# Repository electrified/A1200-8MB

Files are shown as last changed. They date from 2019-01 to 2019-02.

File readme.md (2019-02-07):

# 8MB Fast Ram for A1200

This is a 8MB FastRam board for A1200 designed in 2019 by @edu_arana, coworked with Stephen Leary based on the TF328 project.

# License

This project, as the same as the original, are released under the GNU GPLv2. If you build a modified version of the board you must supply the end user with all the sources (this can be a web link). Also you may create
or base commercial PCBs from the work in this repository but you must make the sources for all derivative work available. The authors on this board must remain and stay legible on the current / new board. Removing the
copyright notices its a breach of the GPL.

BTW, If you make a new board version, we will be glad if you send at least one pcb to each us. This is not a must :p

# Images

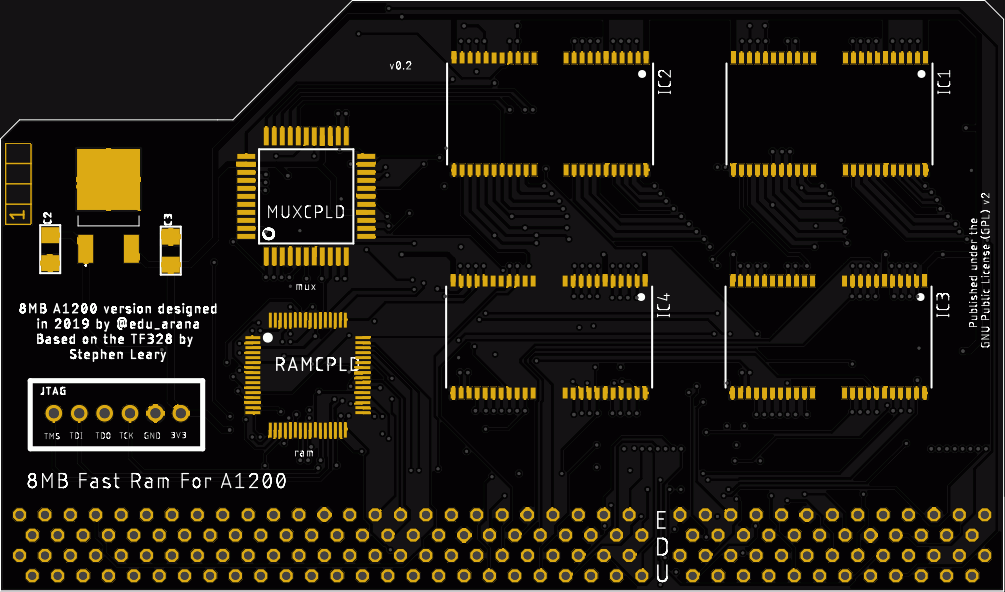
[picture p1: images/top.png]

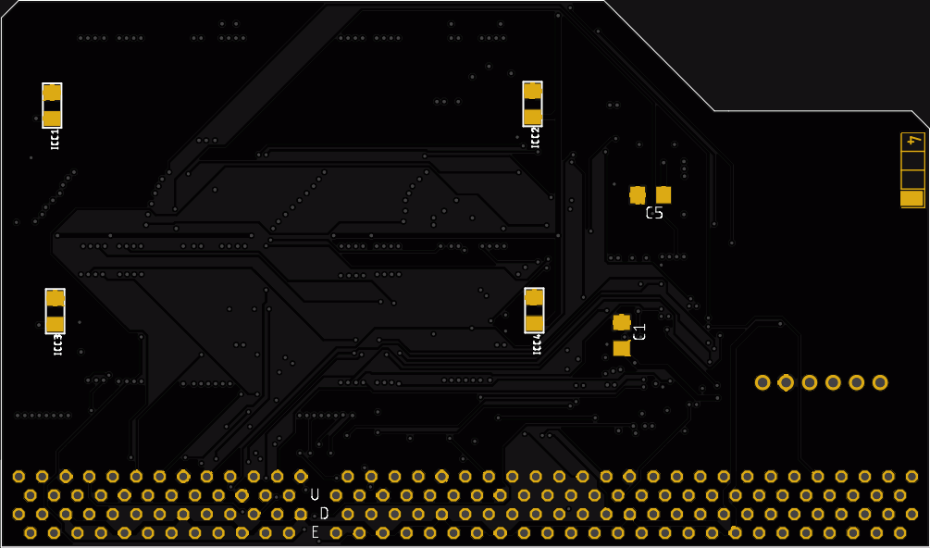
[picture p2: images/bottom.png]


# PCB info (for pcb fabricator)

Dimensions :	59 x 100 mm  
Layers :	4 layers  
Layer order: GTL, G1, G2, GBL  
Finished Copper : 1 oz Cu  
PCB Kinds:	2 (because the breakable area)  
Track/Spacing:	6/6mil  
Blind/Buried Via: No  
Material :	Normal FR-4 Board TG150  
Thickness :	1.6 mm  
Solder Mask :	Whatever color you want :)  
Silkscreen :	Whatever color you want :)  
Surface Finish :Immersion gold (recommended)  
Hole Size :	0.4  

# Firmware:

S. Leary a.k.a terriblefire has made an small modification to the current TF322 to disable the ide option, as the A1200 already have one. The firmware jed files are available on the firmware directory.

Xilinx ISE, 14.7
JTAG Adaptor

Stephen has made a new branch for the firmware used on this board. The current branch address is https://github.com/terriblefire/tf328/tree/edu1200_board

Thanks S.

# Gerbers:

Premade gerbers of the board are available on this repository too.

# Bill of matherials

Note that the only ram chips used and compatible are the K4E151612C, this ram chips are 3v3 only. All the current design is adapter to 3V3. A new LDO regulator is used to get 3V3 vots.

| Part | Value | Package |
| --- | --- | --- |
| C1 | 1uF | 1206 |
| C2 | 10uF | 1206 | 
| C3 | 10uF | 1206 | 
| C5 | 1uF | 1206 |
| CN1 | A1200-EXPANSION_SLOT | CON_150 | 
| IC1 | K4E151612C | TSOP44(50)-II | 
| IC2 | K4E151612C | TSOP44(50)-II | 
| IC3 | K4E151612C | TSOP44(50)-II | 
| IC4 | K4E151612C | TSOP44(50)-II | 
| IC6 | LD39150DT33-R | STD5N52U | 
| ICC1 | 10uF | 1206 | 
| ICC2 | 10uF | 1206 | 
| ICC3 | 10uF | 1206 | 
| ICC4 | 10uF | 1206 | 
| MUXCPLD | XC9536_44VQ | SQFP-S-10X10-44 | 
| RAMCPLD | XC9572XL-VQ64 | VQ64 |

# Wiki

There is a TF328 wiki that can be use to resolve any doubt about the compatibility of the current firmware.

https://github.com/terriblefire/tf328/wiki

# PCMCIA Fix

If you got problems with your PCMCIA device and this upgrade, you can use a free software solution available on aminet called CardReset http://aminet.net/package/util/boot/CardReset

# Contribution / support

If you wanna buy me a beer or a Mercedes SLR,  please contact me at info at arananet.net or support @terriblefire at youtube :)

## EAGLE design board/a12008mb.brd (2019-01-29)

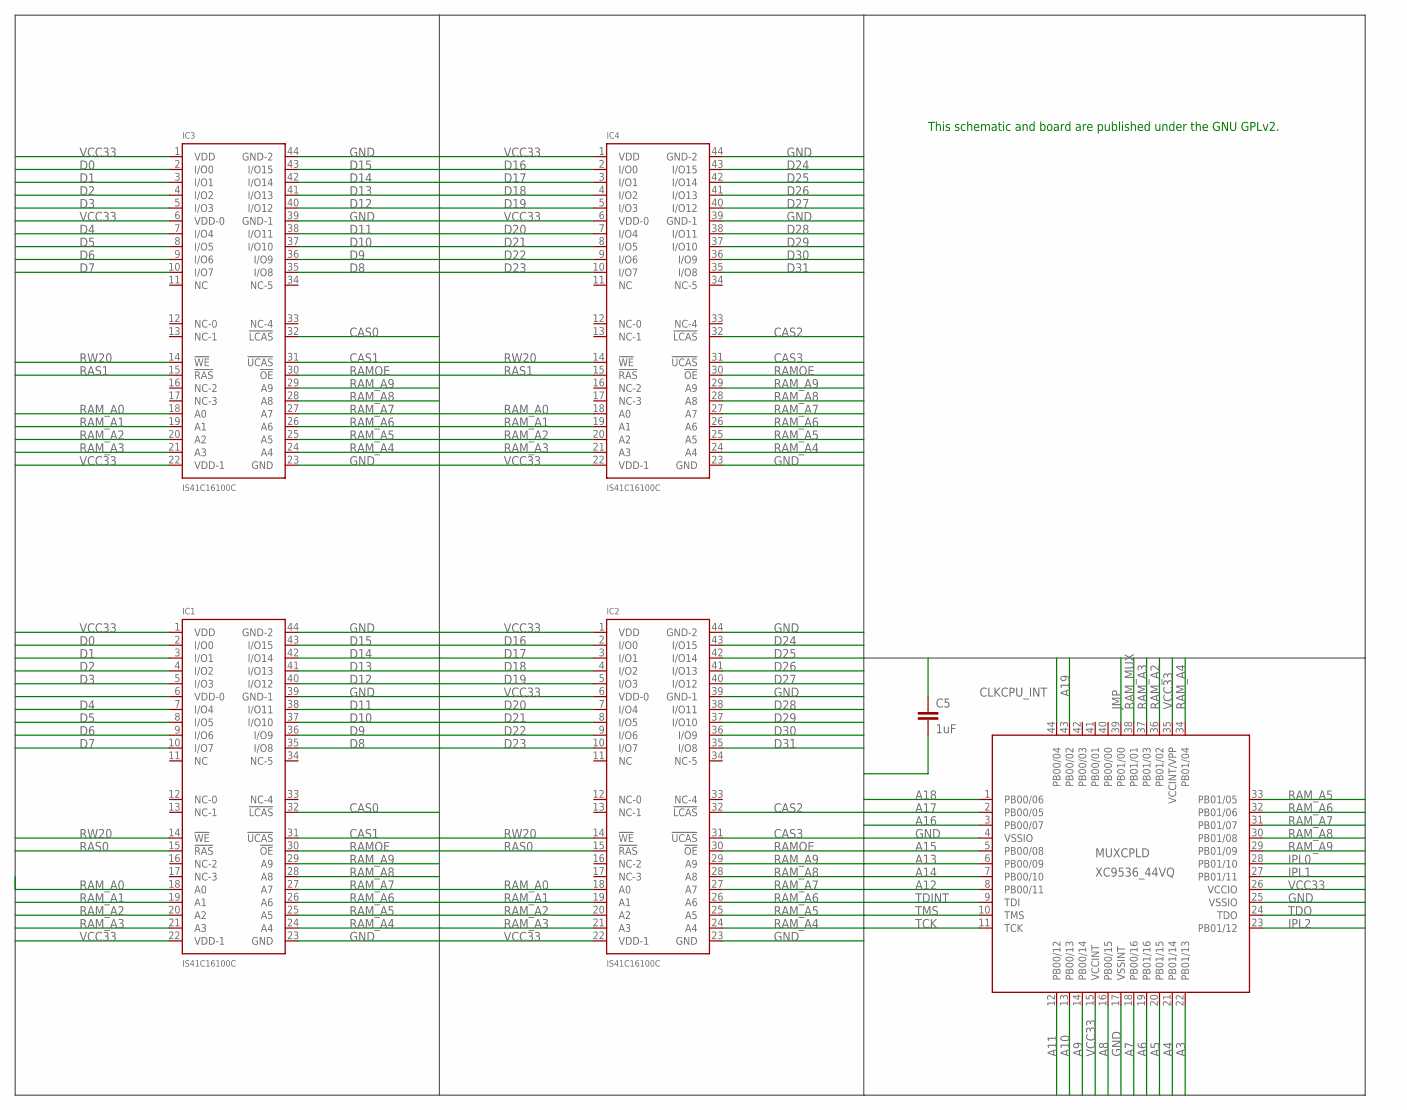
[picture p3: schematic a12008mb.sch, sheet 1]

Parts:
C5: 1uF; C1206
IC1, IC2, IC3, IC4: IS41C16100C; TSOP44(50)-II
MUXCPLD: XC9536_44VQ; SQFP-S-10X10-44

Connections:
A3: MUXCPLD.22 (PB01/13); also elsewhere on the board
A4: MUXCPLD.21 (PB01/14); also elsewhere on the board
A5: MUXCPLD.20 (PB01/15); also elsewhere on the board
A6: MUXCPLD.19 (PB01/16); also elsewhere on the board
A7: MUXCPLD.18 (PB00/16); also elsewhere on the board
A8: MUXCPLD.16 (PB00/15); also elsewhere on the board
A9: MUXCPLD.14 (PB00/14); also elsewhere on the board
A10: MUXCPLD.13 (PB00/13); also elsewhere on the board
A11: MUXCPLD.12 (PB00/12); also elsewhere on the board
A12: MUXCPLD.8 (PB00/11); also elsewhere on the board
A13: MUXCPLD.6 (PB00/09); also elsewhere on the board
A14: MUXCPLD.7 (PB00/10); also elsewhere on the board
A15: MUXCPLD.5 (PB00/08); also elsewhere on the board
A16: MUXCPLD.3 (PB00/07); also elsewhere on the board
A17: MUXCPLD.2 (PB00/05); also elsewhere on the board
A18: MUXCPLD.1 (PB00/06); also elsewhere on the board
A19: MUXCPLD.43 (PB00/02); also elsewhere on the board
CAS0: IC1.32 (!LCAS), IC3.32 (!LCAS); also elsewhere on the board
CAS1: IC1.31 (!UCAS), IC3.31 (!UCAS); also elsewhere on the board
CAS2: IC2.32 (!LCAS), IC4.32 (!LCAS); also elsewhere on the board
CAS3: IC2.31 (!UCAS), IC4.31 (!UCAS); also elsewhere on the board
CLKCPU_INT: MUXCPLD.44 (PB00/04)
D0: IC1.2 (I/O0), IC3.2 (I/O0); also elsewhere on the board
D1: IC1.3 (I/O1), IC3.3 (I/O1); also elsewhere on the board
D2: IC1.4 (I/O2), IC3.4 (I/O2); also elsewhere on the board
D3: IC1.5 (I/O3), IC3.5 (I/O3); also elsewhere on the board
D4: IC1.7 (I/O4), IC3.7 (I/O4); also elsewhere on the board
D5: IC1.8 (I/O5), IC3.8 (I/O5); also elsewhere on the board
D6: IC1.9 (I/O6), IC3.9 (I/O6); also elsewhere on the board
D7: IC1.10 (I/O7), IC3.10 (I/O7); also elsewhere on the board
D8: IC1.35 (I/O8), IC3.35 (I/O8); also elsewhere on the board
D9: IC1.36 (I/O9), IC3.36 (I/O9); also elsewhere on the board
D10: IC1.37 (I/O10), IC3.37 (I/O10); also elsewhere on the board
D11: IC1.38 (I/O11), IC3.38 (I/O11); also elsewhere on the board
D12: IC1.40 (I/O12), IC3.40 (I/O12); also elsewhere on the board
D13: IC1.41 (I/O13), IC3.41 (I/O13); also elsewhere on the board
D14: IC1.42 (I/O14), IC3.42 (I/O14); also elsewhere on the board
D15: IC1.43 (I/O15), IC3.43 (I/O15); also elsewhere on the board
D16: IC2.2 (I/O0), IC4.2 (I/O0); also elsewhere on the board
D17: IC2.3 (I/O1), IC4.3 (I/O1); also elsewhere on the board
D18: IC2.4 (I/O2), IC4.4 (I/O2); also elsewhere on the board
D19: IC2.5 (I/O3), IC4.5 (I/O3); also elsewhere on the board
D20: IC2.7 (I/O4), IC4.7 (I/O4); also elsewhere on the board
D21: IC2.8 (I/O5), IC4.8 (I/O5); also elsewhere on the board
D22: IC2.9 (I/O6), IC4.9 (I/O6); also elsewhere on the board
D23: IC2.10 (I/O7), IC4.10 (I/O7); also elsewhere on the board
D24: IC2.43 (I/O15), IC4.43 (I/O15); also elsewhere on the board
D25: IC2.42 (I/O14), IC4.42 (I/O14); also elsewhere on the board
D26: IC2.41 (I/O13), IC4.41 (I/O13); also elsewhere on the board
D27: IC2.40 (I/O12), IC4.40 (I/O12); also elsewhere on the board
D28: IC2.38 (I/O11), IC4.38 (I/O11); also elsewhere on the board
D29: IC2.37 (I/O10), IC4.37 (I/O10); also elsewhere on the board
D30: IC2.36 (I/O9), IC4.36 (I/O9); also elsewhere on the board
D31: IC2.35 (I/O8), IC4.35 (I/O8); also elsewhere on the board
GND: C5.2, IC1.23 (GND), IC1.39 (GND-1), IC1.44 (GND-2), IC2.23 (GND), IC2.39 (GND-1), IC2.44 (GND-2), IC3.23 (GND), IC3.39 (GND-1), IC3.44 (GND-2), IC4.23 (GND), IC4.39 (GND-1), IC4.44 (GND-2), MUXCPLD.4 (VSSIO), MUXCPLD.17 (VSSINT), MUXCPLD.25 (VSSIO); also elsewhere on the board
IPL0: MUXCPLD.28 (PB01/10); also elsewhere on the board
IPL1: MUXCPLD.27 (PB01/11); also elsewhere on the board
IPL2: MUXCPLD.23 (PB01/12); also elsewhere on the board
JMP: MUXCPLD.39 (PB01/00)
RAMOE: IC1.30 (!OE), IC2.30 (!OE), IC3.30 (!OE), IC4.30 (!OE); also elsewhere on the board
RAM_A0: IC1.18 (A0), IC2.18 (A0), IC3.18 (A0), IC4.18 (A0); also elsewhere on the board
RAM_A1: IC1.19 (A1), IC2.19 (A1), IC3.19 (A1), IC4.19 (A1); also elsewhere on the board
RAM_A2: IC1.20 (A2), IC2.20 (A2), IC3.20 (A2), IC4.20 (A2), MUXCPLD.36 (PB01/02)
RAM_A3: IC1.21 (A3), IC2.21 (A3), IC3.21 (A3), IC4.21 (A3), MUXCPLD.37 (PB01/03)
RAM_A4: IC1.24 (A4), IC2.24 (A4), IC3.24 (A4), IC4.24 (A4), MUXCPLD.34 (PB01/04)
RAM_A5: IC1.25 (A5), IC2.25 (A5), IC3.25 (A5), IC4.25 (A5), MUXCPLD.33 (PB01/05)
RAM_A6: IC1.26 (A6), IC2.26 (A6), IC3.26 (A6), IC4.26 (A6), MUXCPLD.32 (PB01/06)
RAM_A7: IC1.27 (A7), IC2.27 (A7), IC3.27 (A7), IC4.27 (A7), MUXCPLD.31 (PB01/07)
RAM_A8: IC1.28 (A8), IC2.28 (A8), IC3.28 (A8), IC4.28 (A8), MUXCPLD.30 (PB01/08)
RAM_A9: IC1.29 (A9), IC2.29 (A9), IC3.29 (A9), IC4.29 (A9), MUXCPLD.29 (PB01/09)
RAM_MUX: MUXCPLD.38 (PB01/01); also elsewhere on the board
RAS0: IC1.15 (!RAS), IC2.15 (!RAS); also elsewhere on the board
RAS1: IC3.15 (!RAS), IC4.15 (!RAS); also elsewhere on the board
RW20: IC1.14 (!WE), IC2.14 (!WE), IC3.14 (!WE), IC4.14 (!WE); also elsewhere on the board
TCK: MUXCPLD.11 (TCK); also elsewhere on the board
TDINT: MUXCPLD.9 (TDI); also elsewhere on the board
TDO: MUXCPLD.24 (TDO); also elsewhere on the board
TMS: MUXCPLD.10 (TMS); also elsewhere on the board
VCC33: C5.1, IC1.1 (VDD), IC1.6 (VDD-0), IC1.22 (VDD-1), IC2.1 (VDD), IC2.6 (VDD-0), IC2.22 (VDD-1), IC3.1 (VDD), IC3.6 (VDD-0), IC3.22 (VDD-1), IC4.1 (VDD), IC4.6 (VDD-0), IC4.22 (VDD-1), MUXCPLD.15 (VCCINT), MUXCPLD.26 (VCCIO), MUXCPLD.35 (VCCINT/VPP); also elsewhere on the board

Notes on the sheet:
This schematic and board are published under the GNU GPLv2.

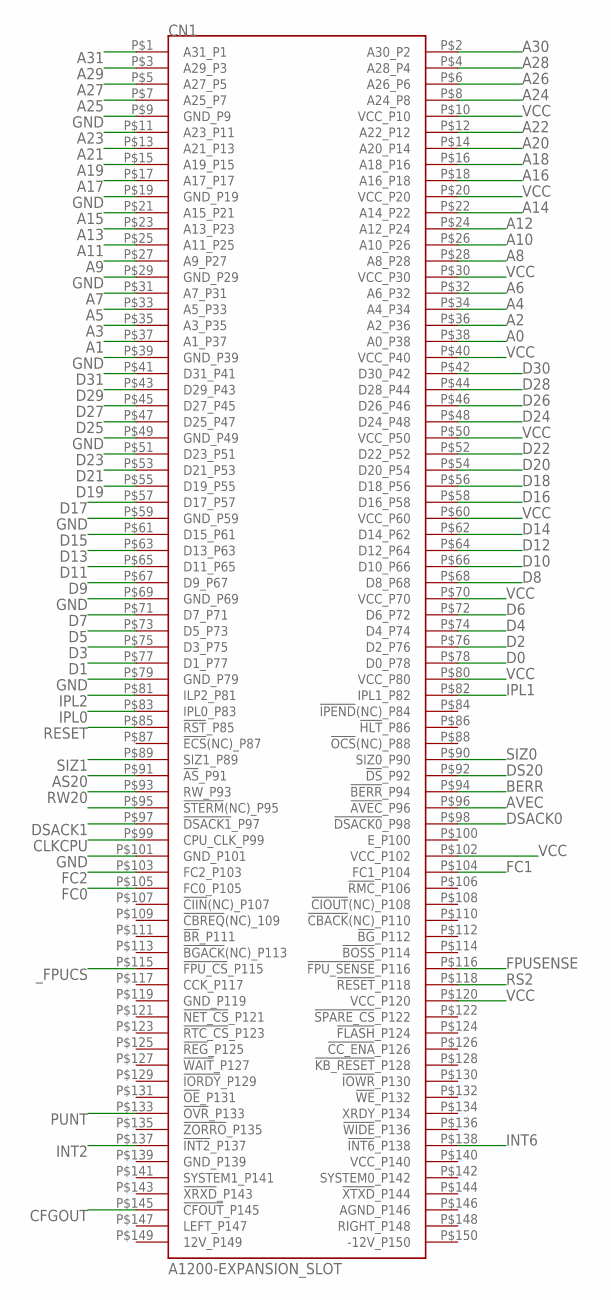
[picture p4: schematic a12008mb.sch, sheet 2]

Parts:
CN1: A1200-EXPANSION_SLOT; CON_150

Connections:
A0: CN1.P$38 (A0_P38); also elsewhere on the board
A1: CN1.P$37 (A1_P37); also elsewhere on the board
A2: CN1.P$36 (A2_P36); also elsewhere on the board
A3: CN1.P$35 (A3_P35); also elsewhere on the board
A4: CN1.P$34 (A4_P34); also elsewhere on the board
A5: CN1.P$33 (A5_P33); also elsewhere on the board
A6: CN1.P$32 (A6_P32); also elsewhere on the board
A7: CN1.P$31 (A7_P31); also elsewhere on the board
A8: CN1.P$28 (A8_P28); also elsewhere on the board
A9: CN1.P$27 (A9_P27); also elsewhere on the board
A10: CN1.P$26 (A10_P26); also elsewhere on the board
A11: CN1.P$25 (A11_P25); also elsewhere on the board
A12: CN1.P$24 (A12_P24); also elsewhere on the board
A13: CN1.P$23 (A13_P23); also elsewhere on the board
A14: CN1.P$22 (A14_P22); also elsewhere on the board
A15: CN1.P$21 (A15_P21); also elsewhere on the board
A16: CN1.P$18 (A16_P18); also elsewhere on the board
A17: CN1.P$17 (A17_P17); also elsewhere on the board
A18: CN1.P$16 (A18_P16); also elsewhere on the board
A19: CN1.P$15 (A19_P15); also elsewhere on the board
A20: CN1.P$14 (A20_P14); also elsewhere on the board
A21: CN1.P$13 (A21_P13); also elsewhere on the board
A22: CN1.P$12 (A22_P12); also elsewhere on the board
A23: CN1.P$11 (A23_P11); also elsewhere on the board
A24: CN1.P$8 (A24_P8)
A25: CN1.P$7 (A25_P7)
A26: CN1.P$6 (A26_P6)
A27: CN1.P$5 (A27_P5)
A28: CN1.P$4 (A28_P4)
A29: CN1.P$3 (A29_P3)
A30: CN1.P$2 (A30_P2)
A31: CN1.P$1 (A31_P1)
AS20: CN1.P$91 (!AS!_P91); also elsewhere on the board
AVEC: CN1.P$96 (!AVEC!_P96)
BERR: CN1.P$94 (!BERR!_P94)
CFGOUT: CN1.P$145 (!CFOUT!_P145)
CLKCPU: CN1.P$99 (CPU_CLK_P99); also elsewhere on the board
D0: CN1.P$78 (D0_P78); also elsewhere on the board
D1: CN1.P$77 (D1_P77); also elsewhere on the board
D2: CN1.P$76 (D2_P76); also elsewhere on the board
D3: CN1.P$75 (D3_P75); also elsewhere on the board
D4: CN1.P$74 (D4_P74); also elsewhere on the board
D5: CN1.P$73 (D5_P73); also elsewhere on the board
D6: CN1.P$72 (D6_P72); also elsewhere on the board
D7: CN1.P$71 (D7_P71); also elsewhere on the board
D8: CN1.P$68 (D8_P68); also elsewhere on the board
D9: CN1.P$67 (D9_P67); also elsewhere on the board
D10: CN1.P$66 (D10_P66); also elsewhere on the board
D11: CN1.P$65 (D11_P65); also elsewhere on the board
D12: CN1.P$64 (D12_P64); also elsewhere on the board
D13: CN1.P$63 (D13_P63); also elsewhere on the board
D14: CN1.P$62 (D14_P62); also elsewhere on the board
D15: CN1.P$61 (D15_P61); also elsewhere on the board
D16: CN1.P$58 (D16_P58); also elsewhere on the board
D17: CN1.P$57 (D17_P57); also elsewhere on the board
D18: CN1.P$56 (D18_P56); also elsewhere on the board
D19: CN1.P$55 (D19_P55); also elsewhere on the board
D20: CN1.P$54 (D20_P54); also elsewhere on the board
D21: CN1.P$53 (D21_P53); also elsewhere on the board
D22: CN1.P$52 (D22_P52); also elsewhere on the board
D23: CN1.P$51 (D23_P51); also elsewhere on the board
D24: CN1.P$48 (D24_P48); also elsewhere on the board
D25: CN1.P$47 (D25_P47); also elsewhere on the board
D26: CN1.P$46 (D26_P46); also elsewhere on the board
D27: CN1.P$45 (D27_P45); also elsewhere on the board
D28: CN1.P$44 (D28_P44); also elsewhere on the board
D29: CN1.P$43 (D29_P43); also elsewhere on the board
D30: CN1.P$42 (D30_P42); also elsewhere on the board
D31: CN1.P$41 (D31_P41); also elsewhere on the board
DS20: CN1.P$92 (!DS!_P92); also elsewhere on the board
DSACK0: CN1.P$98 (!DSACK0!_P98); also elsewhere on the board
DSACK1: CN1.P$97 (!DSACK1!_P97); also elsewhere on the board
FC0: CN1.P$105 (FC0_P105)
FC1: CN1.P$104 (FC1_P104)
FC2: CN1.P$103 (FC2_P103)
FPUSENSE: CN1.P$116 (!FPU_SENSE!_P116)
GND: CN1.P$9 (GND_P9), CN1.P$19 (GND_P19), CN1.P$29 (GND_P29), CN1.P$39 (GND_P39), CN1.P$49 (GND_P49), CN1.P$59 (GND_P59), CN1.P$69 (GND_P69), CN1.P$79 (GND_P79), CN1.P$101 (GND_P101); also elsewhere on the board
INT2: CN1.P$137 (!INT2!_P137); also elsewhere on the board
INT6: CN1.P$138 (!INT6!_P138)
IPL0: CN1.P$83 (IPL0_P83); also elsewhere on the board
IPL1: CN1.P$82 (IPL1_P82); also elsewhere on the board
IPL2: CN1.P$81 (ILP2_P81); also elsewhere on the board
PUNT: CN1.P$133 (!OVR!_P133); also elsewhere on the board
RESET: CN1.P$85 (!RST!_P85); also elsewhere on the board
RS2: CN1.P$118 (!RESET!_P118)
RW20: CN1.P$93 (RW_P93); also elsewhere on the board
SIZ0: CN1.P$90 (SIZ0_P90); also elsewhere on the board
SIZ1: CN1.P$89 (SIZ1_P89); also elsewhere on the board
VCC: CN1.P$10 (VCC_P10), CN1.P$20 (VCC_P20), CN1.P$30 (VCC_P30), CN1.P$40 (VCC_P40), CN1.P$50 (VCC_P50), CN1.P$60 (VCC_P60), CN1.P$70 (VCC_P70), CN1.P$80 (VCC_P80), CN1.P$102 (VCC_P102), CN1.P$120 (VCC_P120); also elsewhere on the board
_FPUCS: CN1.P$115 (!FPU_CS!_P115)

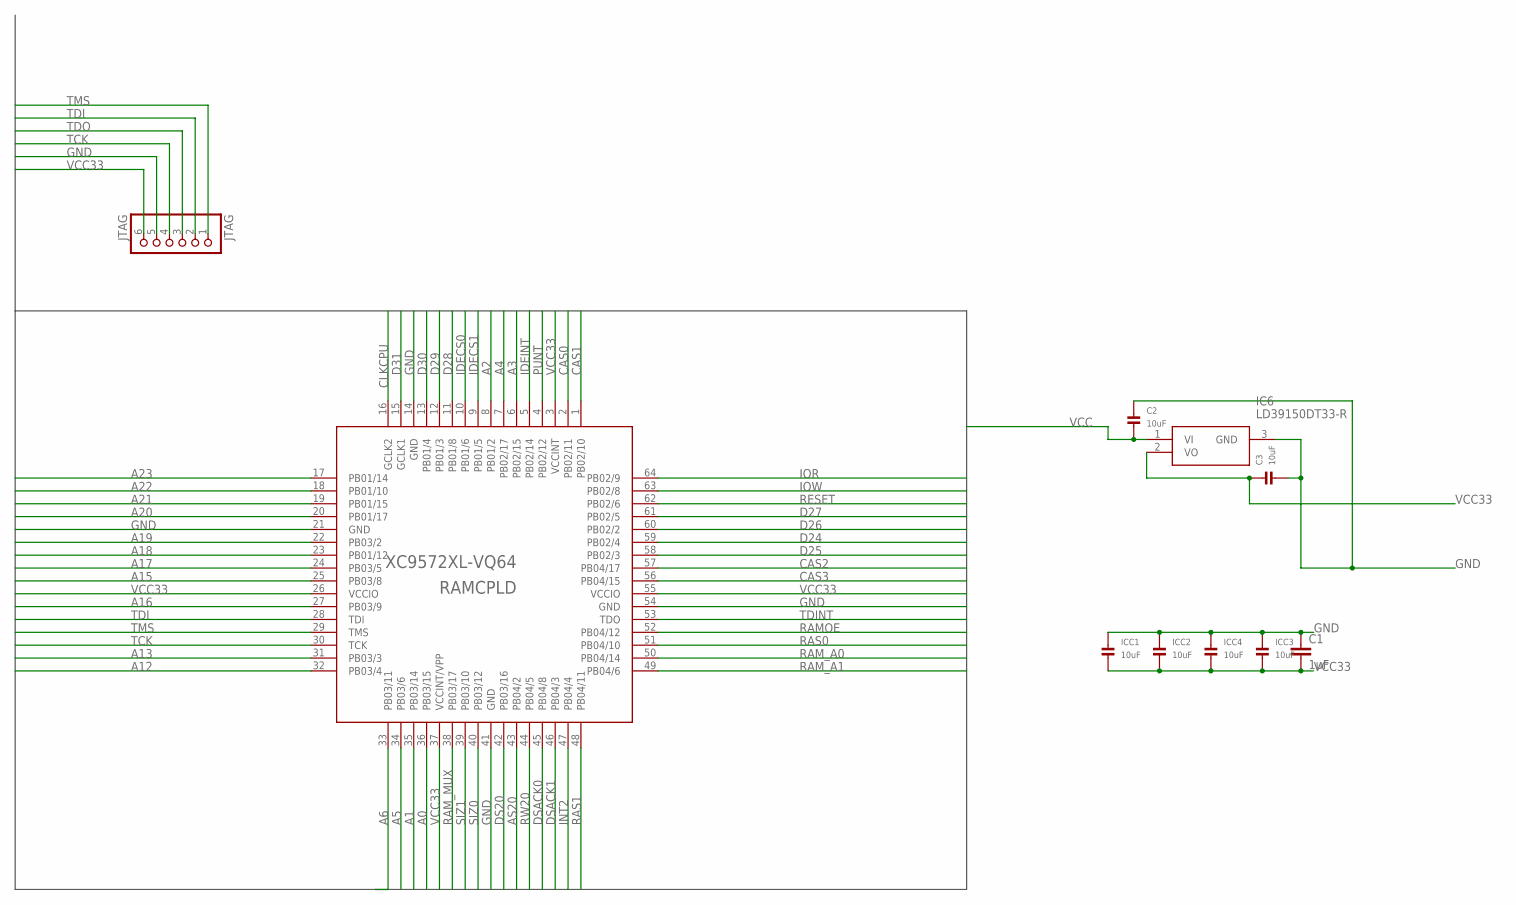
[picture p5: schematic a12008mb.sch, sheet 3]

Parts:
C1: 1uF; C1206
C2, C3: 10uF; 1206
IC6: LD39150DT33-R; STD5N52U
ICC1, ICC2, ICC3, ICC4: 10uF; 1206
JTAG: JTAG; 1X06_ROUND
RAMCPLD: XC9572XL-VQ64; VQ64

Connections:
A0: RAMCPLD.36 (PB03/15); also elsewhere on the board
A1: RAMCPLD.35 (PB03/14); also elsewhere on the board
A2: RAMCPLD.8 (PB01/2); also elsewhere on the board
A3: RAMCPLD.6 (PB02/15); also elsewhere on the board
A4: RAMCPLD.7 (PB02/17); also elsewhere on the board
A5: RAMCPLD.34 (PB03/6); also elsewhere on the board
A6: RAMCPLD.33 (PB03/11); also elsewhere on the board
A12: RAMCPLD.32 (PB03/4); also elsewhere on the board
A13: RAMCPLD.31 (PB03/3); also elsewhere on the board
A15: RAMCPLD.25 (PB03/8); also elsewhere on the board
A16: RAMCPLD.27 (PB03/9); also elsewhere on the board
A17: RAMCPLD.24 (PB03/5); also elsewhere on the board
A18: RAMCPLD.23 (PB01/12); also elsewhere on the board
A19: RAMCPLD.22 (PB03/2); also elsewhere on the board
A20: RAMCPLD.20 (PB01/17); also elsewhere on the board
A21: RAMCPLD.19 (PB01/15); also elsewhere on the board
A22: RAMCPLD.18 (PB01/10); also elsewhere on the board
A23: RAMCPLD.17 (PB01/14); also elsewhere on the board
AS20: RAMCPLD.43 (PB04/2); also elsewhere on the board
CAS0: RAMCPLD.2 (PB02/11); also elsewhere on the board
CAS1: RAMCPLD.1 (PB02/10); also elsewhere on the board
CAS2: RAMCPLD.57 (PB04/17); also elsewhere on the board
CAS3: RAMCPLD.56 (PB04/15); also elsewhere on the board
CLKCPU: RAMCPLD.16 (GCLK2); also elsewhere on the board
D24: RAMCPLD.59 (PB02/4); also elsewhere on the board
D25: RAMCPLD.58 (PB02/3); also elsewhere on the board
D26: RAMCPLD.60 (PB02/2); also elsewhere on the board
D27: RAMCPLD.61 (PB02/5); also elsewhere on the board
D28: RAMCPLD.11 (PB01/8); also elsewhere on the board
D29: RAMCPLD.12 (PB01/3); also elsewhere on the board
D30: RAMCPLD.13 (PB01/4); also elsewhere on the board
D31: RAMCPLD.15 (GCLK1); also elsewhere on the board
DS20: RAMCPLD.42 (PB03/16); also elsewhere on the board
DSACK0: RAMCPLD.45 (PB04/8); also elsewhere on the board
DSACK1: RAMCPLD.46 (PB04/3); also elsewhere on the board
GND: C1.1, C2.1, C3.2, IC6.3 (GND), ICC1.1, ICC2.1, ICC3.1, ICC4.1, JTAG.5, RAMCPLD.14 (GND), RAMCPLD.21 (GND), RAMCPLD.41 (GND), RAMCPLD.54 (GND); also elsewhere on the board
IDECS0: RAMCPLD.10 (PB01/6)
IDECS1: RAMCPLD.9 (PB01/5)
IDEINT: RAMCPLD.5 (PB02/14)
INT2: RAMCPLD.47 (PB04/4); also elsewhere on the board
IOR: RAMCPLD.64 (PB02/9)
IOW: RAMCPLD.63 (PB02/8)
PUNT: RAMCPLD.4 (PB02/12); also elsewhere on the board
RAMOE: RAMCPLD.52 (PB04/12); also elsewhere on the board
RAM_A0: RAMCPLD.50 (PB04/14); also elsewhere on the board
RAM_A1: RAMCPLD.49 (PB04/6); also elsewhere on the board
RAM_MUX: RAMCPLD.38 (PB03/17); also elsewhere on the board
RAS0: RAMCPLD.51 (PB04/10); also elsewhere on the board
RAS1: RAMCPLD.48 (PB04/11); also elsewhere on the board
RESET: RAMCPLD.62 (PB02/6); also elsewhere on the board
RW20: RAMCPLD.44 (PB04/5); also elsewhere on the board
SIZ0: RAMCPLD.40 (PB03/12); also elsewhere on the board
SIZ1: RAMCPLD.39 (PB03/10); also elsewhere on the board
TCK: JTAG.4, RAMCPLD.30 (TCK); also elsewhere on the board
TDI: JTAG.2, RAMCPLD.28 (TDI)
TDINT: RAMCPLD.53 (TDO); also elsewhere on the board
TDO: JTAG.3; also elsewhere on the board
TMS: JTAG.1, RAMCPLD.29 (TMS); also elsewhere on the board
VCC: C2.2, IC6.1 (VI); also elsewhere on the board
VCC33: C1.2, C3.1, IC6.2 (VO), ICC1.2, ICC2.2, ICC3.2, ICC4.2, JTAG.6, RAMCPLD.3 (VCCINT), RAMCPLD.26 (VCCIO), RAMCPLD.37 (VCCINT/VPP), RAMCPLD.55 (VCCIO); also elsewhere on the board

Board: 4 copper layers, 17 parts (7 on the bottom side), 96 nets, no tracks yet.

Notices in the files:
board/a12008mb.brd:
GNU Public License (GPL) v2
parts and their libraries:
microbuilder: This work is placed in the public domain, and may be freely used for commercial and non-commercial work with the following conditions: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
